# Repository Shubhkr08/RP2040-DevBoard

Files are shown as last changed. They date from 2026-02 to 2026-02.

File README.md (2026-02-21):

# RP2040-DevBoard
I made a custom devboard based on RP2040 chip ,it has a USB type C  and the design utilizes most of its gpio pins , I did the Schematic and PCB design in Kicad and renders in Fusion.
## Overview
I started by looking at the guide project and did the schematics , choose the particular footprint as per guided and ended up with a proper schematics which acted as the base to the project,
then I started up with placing every particular components in a systematic way as (decoupling capacitors are close to there connected pins) as well as they are well arranged so that I don't have to deal with much problem while Routing afterwards. I kept a proper look to all components as they are placed in there specific area and has there required footprint, after that I Started with routing the PCB ,there were many problem that i came across like no space for rounding the wires, misconnection, no space for Via but i dealt with the problem, did multiple alterations while routing and ended up with a properly finished Rp2040 Devboard
## Features
- RP2040 Chip Based
- 2-layer compact PCB
- Most of the gpio avialable 
- USB connection for programming and power
- Onboard  voltage regulation
- Compact footprint for small projects
- Educational focus for learning MCU integration and PCB design

## 🧾 Bill of Materials (BOM)

| Qty | Manufacturer Part Number | Description | Supplier | Unit Price (USD) | Total (USD) |
|-----|---|---|---|---|---|
| 2 | C0402C105K9PACTU | CAP CER 1UF 6.3V X5R 0402 | DigiKey.in | 0.08000 | 0.16 |
| 11 | 0402B104K160CT | CAP CER 0.1UF 16V X7R 0402 | DigiKey.in | 0.00300 | 0.03 |
| 2 | LMK107BBJ106MALT | CAP CER 10UF 10V X5R 0603 | DigiKey.in | 0.08000 | 0.16 |
| 2 | CL05C330JB5NNNC | CAP CER 33PF 50V C0G/NP0 0402 | DigiKey.in | 0.10000 | 0.20 |
| 1 | USB4215-03-A | USB C RECEPTAC, SHT BODY, USB2.0 | DigiKey.in | 0.49000 | 0.49 |
| 2 | RC0402FR-075K1L | RES 5.1K OHM 1% 1/16W 0402 | DigiKey.in | 0.10000 | 0.20 |
| 2 | ERA-2AEB273X | RES SMD 27K OHM 0.1% 1/16W 0402 | DigiKey.in | 0.10000 | 0.20 |
| 2 | RMCF0603FT1K00 | RES 1K OHM 1% 1/10W 0603 | DigiKey.in | 0.10000 | 0.20 |
| 1 | RC0201FR-0710KL | RES 10K OHM 1% 1/20W 0201 | DigiKey.in | 0.10000 | 0.10 |
| 1 | SW-PB9-AB00AQE-5 | Subminiature Pushbutton Switch | DigiKey.in | 3.39000 | 3.39 |
| 1 | SC0914(13) | IC MCU 32B EXT MEM 56QFN RP2040 | DigiKey.in | 0.70000 | 0.70 |
| 1 | MCP1700T-3302E/TT | IC REG LINEAR 3.3V 250MA SOT23-3 | DigiKey.in | 0.51000 | 0.51 |
| 1 | AT24CS02-SSHM-T | IC EEPROM 2KBIT I2C 1MHZ 8SOIC | DigiKey.in | 0.31000 | 0.31 |
| 1 | STDCRA3-8M | CRYSTAL 8.0000MHZ 8PF SMD | DigiKey.in | 0.84000 | 0.84 |
| 2 | DW-10-15-T-D-420-LL | CONN HDR 20POS 0.1 STACK T/H TIN | DigiKey.in | 1.99000 | 3.98 |

---

## 💰 Cost Breakdown

| Item | Cost (USD) |
|---|---|
| Parts Total (DigiKey) | 11.47 |
| DigiKey Shipping | 20.00 |
| JLCPCB + Stencil | 11.47 |
| JLCPCB Shipping | 25.11 |
| Discount | -5.00 |
| **Grand Total** | **63.05 USD** |

---

### 🧮 Final Total: **$63.05 USD**

## Schematic & PCB
<br>Screenshot (108)<br>
<br>Screenshot (118)
<br>

 ## 3d Render
<br>Screenshot (111)
<br>
<br>Screenshot (116)
<br>
<br>Screenshot (115)
 <br>

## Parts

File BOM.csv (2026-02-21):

Category | Quantity | Manufacturer Part Number | Description | Supplier | Unit Price (USD) | Total (USD)
Component | 2 | C0402C105K9PACTU | CAP CER 1UF 6.3V X5R 0402 | DigiKey.in | 0.08000 | 0.16
Component | 11 | 0402B104K160CT | CAP CER 0.1UF 16V X7R 0402 | DigiKey.in | 0.00300 | 0.03
Component | 2 | LMK107BBJ106MALT | CAP CER 10UF 10V X5R 0603 | DigiKey.in | 0.08000 | 0.16
Component | 2 | CL05C330JB5NNNC | CAP CER 33PF 50V C0G/NP0 0402 | DigiKey.in | 0.10000 | 0.20
Component | 1 | USB4215-03-A | USB C RECEPTAC USB2.0 | DigiKey.in | 0.49000 | 0.49
Component | 2 | RC0402FR-075K1L | RES 5.1K OHM 1% 0402 | DigiKey.in | 0.10000 | 0.20
Component | 2 | ERA-2AEB273X | RES 27K OHM 0.1% 0402 | DigiKey.in | 0.10000 | 0.20
Component | 2 | RMCF0603FT1K00 | RES 1K OHM 1% 0603 | DigiKey.in | 0.10000 | 0.20
Component | 1 | RC0201FR-0710KL | RES 10K OHM 1% 0201 | DigiKey.in | 0.10000 | 0.10
Component | 1 | SW-PB9-AB00AQE-5 | Pushbutton Switch | DigiKey.in | 3.39000 | 3.39
Component | 1 | SC0914(13) | RP2040 Microcontroller | DigiKey.in | 0.70000 | 0.70
Component | 1 | MCP1700T-3302E/TT | 3.3V Voltage Regulator | DigiKey.in | 0.51000 | 0.51
Component | 1 | AT24CS02-SSHM-T | 2Kbit I2C EEPROM | DigiKey.in | 0.31000 | 0.31
Component | 1 | STDCRA3-8M | 8MHz Crystal | DigiKey.in | 0.84000 | 0.84
Component | 2 | DW-10-15-T-D-420-LL | 20POS Header Connector | DigiKey.in | 1.99000 | 3.98
Service | 1 | DIGIKEY-SHIPPING | DigiKey Shipping | DigiKey.in | 20.00 | 20.00
Service | 1 | JLCPCB-PCB-STENCIL | JLCPCB PCB + Stencil | JLCPCB | 11.47 | 11.47
Service | 1 | JLCPCB-SHIPPING | JLCPCB Shipping | JLCPCB | 25.11 | 25.11
 |  |  |  |  | Grand Total (USD) | 68.05

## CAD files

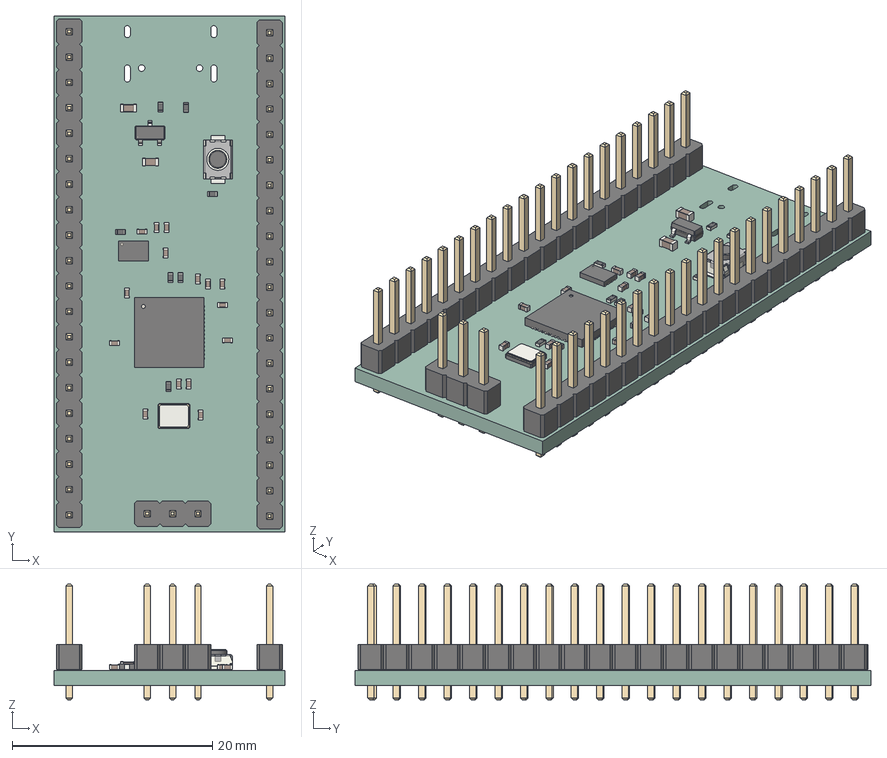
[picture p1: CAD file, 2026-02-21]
RP2040 DevBoard/CAD/RP2040 DevBoard.step
23.0 x 51.5 x 11.5 mm
QFN-56-1EP_7x7mm_P0.4mm_EP3.2x3.2mm
C_0402_1005Metric x 15
R_0402_1005Metric x 7
C_0603_1608Metric x 2
PinHeader_1x20_P2.54mm_Vertical x 2
Winbond_USON-8-1EP_3x2mm_P0.5mm_EP0.2x1.6mm
PinHeader_1x03_P2.54mm_Vertical
SOT-23
Crystal_SMD_3225-4Pin_3.2x2.5mm
SW_Push_SPST_NO_Alps_SKRK
RP2040 DevBoard_PCB

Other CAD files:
RP2040 DevBoard/CAD/RP2040 DevBoard.f3d

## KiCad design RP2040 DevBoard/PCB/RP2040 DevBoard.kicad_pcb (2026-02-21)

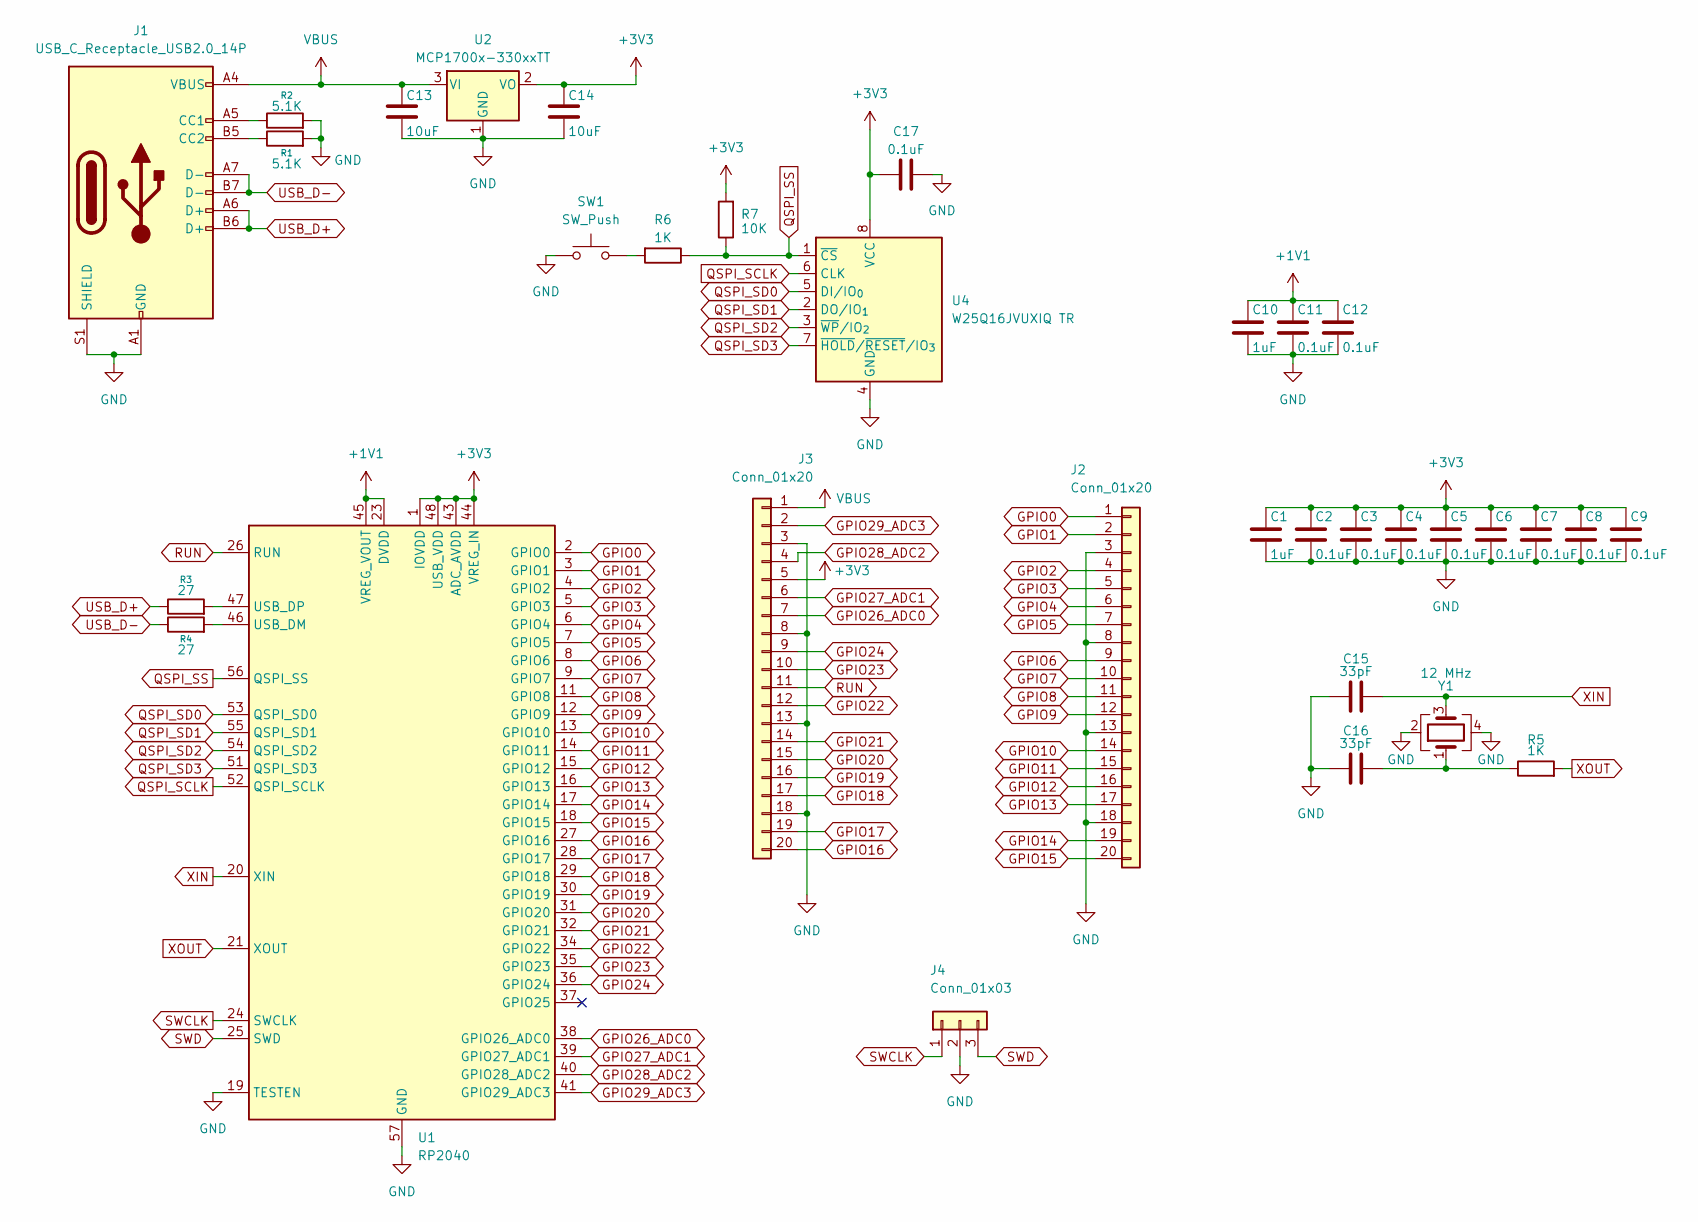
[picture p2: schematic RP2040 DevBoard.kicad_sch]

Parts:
C1, C10: 1uF; C_0402_1005Metric
C2, C3, C4, C5, C6, C7, C8, C9, C11, C12, C17: 0.1uF; C_0402_1005Metric
C13, C14: 10uF; C_0603_1608Metric
C15, C16: 33pF; C_0402_1005Metric
J1: USB_C_Receptacle_USB2.0_14P; USB_C_Receptacle_HRO_TYPE-C-31-M-12
J2, J3: Conn_01x20; PinHeader_1x20_P2.54mm_Vertical
J4: Conn_01x03; PinHeader_1x03_P2.54mm_Vertical
R1, R2: 5.1K; R_0402_1005Metric
R3, R4: 27; R_0402_1005Metric
R5, R6: 1K; R_0402_1005Metric
R7: 10K; R_0402_1005Metric
SW1: SW_Push; SW_Push_SPST_NO_Alps_SKRK
U1: RP2040; QFN-56-1EP_7x7mm_P0.4mm_EP3.2x3.2mm
U2: MCP1700x-330xxTT; SOT-23
U4: W25Q16JVUXIQ TR; Winbond_USON-8-1EP_3x2mm_P0.5mm_EP0.2x1.6mm
Y1: 12 MHz; Crystal_SMD_3225-4Pin_3.2x2.5mm

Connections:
+1V1: C10.1, C11.1, C12.1, U1.23 (DVDD), U1.45 (VREG_VOUT), U1.50 (DVDD)
+3V3: C1.1, C2.1, C3.1, C4.1, C5.1, C6.1, C7.1, C8.1, C9.1, C14.1, C17.1, J3.5, R7.2, U1.1 (IOVDD), U1.10 (IOVDD), U1.22 (IOVDD), U1.33 (IOVDD), U1.42 (IOVDD), U1.43 (ADC_AVDD), U1.44 (VREG_IN), U1.48 (USB_VDD), U1.49 (IOVDD), U2.2 (VO), U4.8 (VCC)
GND: C1.2, C2.2, C3.2, C4.2, C5.2, C6.2, C7.2, C8.2, C9.2, C10.2, C11.2, C12.2, C13.2, C14.2, C15.1, C16.1, C17.2, J1.A1 (GND), J1.A12 (GND), J1.B1 (GND), J1.B12 (GND), J1.S1 (SHIELD), J2.3, J2.8, J2.13, J2.18, J3.3, J3.8, J3.13, J3.18, J4.2, R1.2, R2.2, SW1.1, U1.19 (TESTEN), U1.57 (GND), U2.1 (GND), U4.4 (GND), Y1.2, Y1.4
GPIO0: J2.1, U1.2 (GPIO0)
GPIO1: J2.2, U1.3 (GPIO1)
GPIO2: J2.4, U1.4 (GPIO2)
GPIO3: J2.5, U1.5 (GPIO3)
GPIO4: J2.6, U1.6 (GPIO4)
GPIO5: J2.7, U1.7 (GPIO5)
GPIO6: J2.9, U1.8 (GPIO6)
GPIO7: J2.10, U1.9 (GPIO7)
GPIO8: J2.11, U1.11 (GPIO8)
GPIO9: J2.12, U1.12 (GPIO9)
GPIO10: J2.14, U1.13 (GPIO10)
GPIO11: J2.15, U1.14 (GPIO11)
GPIO12: J2.16, U1.15 (GPIO12)
GPIO13: J2.17, U1.16 (GPIO13)
GPIO14: J2.19, U1.17 (GPIO14)
GPIO15: J2.20, U1.18 (GPIO15)
GPIO16: J3.20, U1.27 (GPIO16)
GPIO17: J3.19, U1.28 (GPIO17)
GPIO18: J3.17, U1.29 (GPIO18)
GPIO19: J3.16, U1.30 (GPIO19)
GPIO20: J3.15, U1.31 (GPIO20)
GPIO21: J3.14, U1.32 (GPIO21)
GPIO22: J3.12, U1.34 (GPIO22)
GPIO23: J3.10, U1.35 (GPIO23)
GPIO24: J3.9, U1.36 (GPIO24)
GPIO26_ADC0: J3.7, U1.38 (GPIO26_ADC0)
GPIO27_ADC1: J3.6, U1.39 (GPIO27_ADC1)
GPIO28_ADC2: J3.4, U1.40 (GPIO28_ADC2)
GPIO29_ADC3: J3.2, U1.41 (GPIO29_ADC3)
unnamed: C16.2, R5.1, Y1.1
unnamed: J1.A5 (CC1), R2.1
unnamed: J1.B5 (CC2), R1.1
unnamed: R6.2, SW1.2
unnamed: R4.2, U1.46 (USB_DM)
unnamed: R3.2, U1.47 (USB_DP)
QSPI_SCLK: U1.52 (QSPI_SCLK), U4.6 (CLK)
QSPI_SD0: U1.53 (QSPI_SD0), U4.5 (DI/IO_{0})
QSPI_SD1: U1.55 (QSPI_SD1), U4.2 (DO/IO_{1})
QSPI_SD2: U1.54 (QSPI_SD2), U4.3 (~WP/IO_{2})
QSPI_SD3: U1.51 (QSPI_SD3), U4.7 (~HOLD/~RESET/IO_{3})
QSPI_SS: R6.1, R7.1, U1.56 (QSPI_SS), U4.1 (~CS)
RUN: J3.11, U1.26 (RUN)
SWCLK: J4.1, U1.24 (SWCLK)
SWD: J4.3, U1.25 (SWD)
USB_D+: J1.A6 (D+), J1.B6 (D+), R3.1
USB_D-: J1.A7 (D-), J1.B7 (D-), R4.1
VBUS: C13.1, J1.A4 (VBUS), J1.A9 (VBUS), J1.B4 (VBUS), J1.B9 (VBUS), J3.1, U2.3 (VI)
XIN: C15.2, U1.20 (XIN), Y1.3
XOUT: R5.2, U1.21 (XOUT)

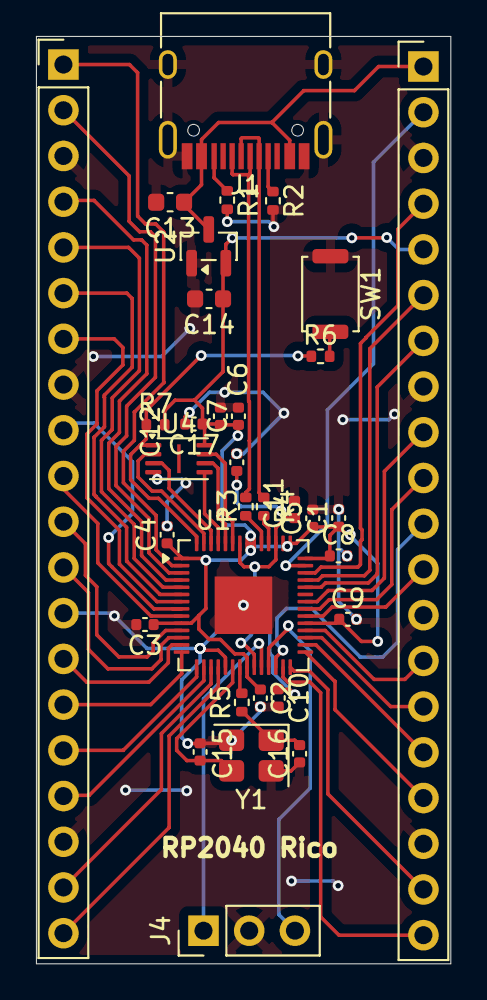
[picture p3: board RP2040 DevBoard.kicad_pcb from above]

Board: 2 copper layers, 23.0 x 51.5 mm, 33 parts (0 on the bottom side), 52 nets.
